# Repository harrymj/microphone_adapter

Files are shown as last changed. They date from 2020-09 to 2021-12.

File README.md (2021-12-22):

# <div align="center">Microphone Adapter</div>

[Link to project page on AJ6ME Radios Website](https://sites.google.com/aj6me.com/aj6me-radios/kw-microphone-adapter)

This project is not affiliated with Kenwood, nor endorsed by them. All references to the TM-D710GA here only indicate the personal radio the author originally designed the project for.

## Introduction
Standard solutions to enable external headsets for the TM-D710GA and similar amateur radios involve using adapter harnesses and/or large mechanical switch boxes. The handheld microphone's buttons (necessary for VFO direct entry) are not usable at the same time as the headset.

This project allows simultaneous connection of both a standard handheld microphone and a headset mic (3.5mm)/PTT (1/4") combination. A solid state audio switch automatically switches between the two microphone inputs depending on which PTT is pressed. 

The board above will be housed in an extruded aluminum enclosure with endcaps with custom cutouts for the connectors. The aluminum enclosure will be plated in a conductive material for good EMI shielding.

### Tooling
This project is designed in Altium Designer. I recognize and apologize that this isn't the most common/portable tool for open-source hardware, but it's the one that I'm the most familiar and comfortable with. Altium provides a [free, no-login web-based viewer](https://www.altium.com/viewer/) that enables viewing/probing the schematics and layout and viewing the 3D model of the finished board. The schematic is also exported as a PDF in the PCBA (assembly) manufacturing outputs folder.

A quick note about version schemes: Traditionally I've used a scheme project_name_x-y-z where x,y,z are integers incrementing from 0. X increments if there's a major architectural change to the project. Y increments if the PCB fab changes (copper/silkscreen/etc). Z changes for different component stuffing options on the same board. X and Y are tracked for the folder in the filenames, and Z is tracked as a 'variant' in the toolchain. As of now, each copper rev is stored in a different folder. If I eventually decide to get more seriously into git and try to manage releases in the tool, that may change. 

## Implementation

### Radio Connector Pinout (1:1 to Handheld Mic)
| Standard RJ45 Pin # | Kenwood Pin # | Function |
| --- | --- | --- |
| 1 | 8 | Keypad |
| 2 | 7 | Hook (GND when on hanger) |
| 3 | 6 | MIC |
| 4 | 5 | MIC-E (Shield) |
| 5 | 4 | PTT |
| 6 | 3 | GND |
| 7 | 2 | SB (8V Power Rail) |
| 8 | 1 | No Connect |

### Schematic
Allmost all signals are run through 1:1 between the Radio and Handheld Mic connector. The exceptions are:

Shield and board GND are tied together: this is also done on the radio side so there's the potential for a ground loop, but the area is only between two adjacent pairs on an RJ45 cable. As a benefit, this merging of grounds means that the enclosure (conductive aluminum) can be more effectively bonded to the shield/outer contact of all connectors, which should reduce radiated susceptibility.

Hook is not connected (though there's a resistor stuffing option to connect it if you wish). If connected, this would disable all transmit (even headset transmit) when the handheld mic is on its hanger.

The microphone signal is muxed between the handheld mic and the headset mic using a [TS5A22364DGSR](https://datasheet.ciiva.com/1671/ts5a22362-1671776.pdf?src-supplier=Digi-Key) analog switch. This switch is a single-supply (only a single positive 5V supply) analog switch that still allows for negative switched voltages (down to -500mV given the 5V supply) at low THD.

The select input of this analog switch is set using the Headset PTT signal. If the Headset PTT is pressed, the switch will connect the Headset microphone input to the radio. If the Headset PTT isn't pressed (regardless of whether the handheld mic PTT is being pressed) the handheld mic will be connected to the radio. When the headset PTT is pressed, D1 pulls down the main PTT line to key up the radio. When the handheld mic is pressed, the main PTT signal goes low (keying the radio), but because of D1, the Headset PTT line is not pulled low (ensuring the handheld mic is connected).

### Layout
The board is 4 layers. All components are placed on L1, so this is a two-step assembly process of first mounting and reflowing the SMT components, then placing and soldering (by hand, wave, selective wave, etc) the through-hole components. Surface-mount versions of these connectors do exist, but the designer generally avoids them due to mechanical robustness concerns (large connectors only mounted on surface-mount pads tend to be easier to rip out of the board than connectors that are staked through the board).

Audio signals are run (as much as feasible) on Layer 2, where they can be surrounded by GND planes on L1, L2, and L3. Ground Plane stitching vias are used to ensure these three planes stay at the same voltage.

On the two non-connector faces, grounded copper strips are exposed (likely, the sides of the boards there will be plated as well) to enable good connection to the conductive enclosure.

### Enclosure
Vendor selection and prototyping for the enclosure is still ongoing, but will take the form of an aluminum extrusion plus cutout-endplates for the connector faces. Designer is targeting a Trivalent Chromium plating on the enclosure to make it conductive for better connection to the shields of the connectors. When available, manufacturer's drawings will be uploaded.

### Board to Radio Cable
While a standard 1:1 RJ45 Ethernet cable should work here, the Keypad signal is an oscillating square-wave signal at some number of kHz. This can inject a decent chunk of noise into the radio. Testing is still ongoing to determine the best way to manage this (different pinout cable, standard shielded patch cable, shielded custom pinout patch cable, etc.)

### Manufacturing Outputs
Full sets of manufacuring files (ODB++, Gerbers/NC Drill, BOM, pick & place, schematic PDF, and 3d step file) for the PCBs are (or will be when complete) included in the respective subfolders. As referred to in the introductory note above, there are two types of manufacturing output folders: PCB (bare fab) and PCBA (assembled board). The PCB manufacturing outputs will take the form of microphone_adapter_1-y where y is the copper revision number. PCBA manufacturing outputs will take the form of microphone_adapter_1-y-z where y still represents copper revision number, and z represents component stuffing revision number.

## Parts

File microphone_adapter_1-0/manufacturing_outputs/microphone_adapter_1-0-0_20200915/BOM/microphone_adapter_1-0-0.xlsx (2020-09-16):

Designator | Quantity | Manufacturer Part Number | Description | Comment | Footprint
C1, C2 | 2 | GRM21A5C2E220JW01D | CAP CER 22PF 250V C0G/NP0 0805 | GRM21A5C2E220JW01D | C0805_1.00MM
C3, C4 | 2 | GRM155C81E105ME11D | CAP CER 1UF 25V X6S 0402 | GRM155C81E105ME11D | C0402_0.55MM
D1 | 1 | BAT54XV2T1G | ON Semi BAT54XV2T1G; SMT Schottky Diode; 30V 200mA; 5ns; 2-Pin SOD-523 | BAT54XV2T1G | SOD523_ONSEMI
J1, J2 | 2 | RJHSE-5480 | Conn RJ-45 F 8 POS 2.03mm Solder RA Thru-Hole 8 Terminal 1 Port Tray Cat 5 | RJHSE-5480 | ETH_RJ45_RA_RJHSE-5480
J3 | 1 | MJ-3536 | CONN JACK MONO 3.5MM R/A | MJ-3536 | AUD_CUI_MJ-3536
J4 | 1 | RN112BPC | CONN JACK STEREO 0.25" (6.35MM) R/A | RN112BPC | AUD_SWITCHCRAFT_RN112BPC
R1 | 1 | RC0402FR-074K7L | RES SMD 4.7K OHM 1% 1/16W 0402 | RC0402FR-074K7L | R0402_0.40MM
U1 | 1 | TS5A22364DGSR | TEXAS INSTRUMENTS TS5A22364DGSR. ANALOG SWITCH, DUAL, SPDT, MSOP-10 | TS5A22364DGSR | TI_VSSOP_10_DGS0010A
U2 | 1 | AP7370-50W5-7 | LDO Regulator Pos 5V 0.3A 5-Pin SOT-25 T/R | AP7370-50W5-7 | DIODES_INC_SOT25_5

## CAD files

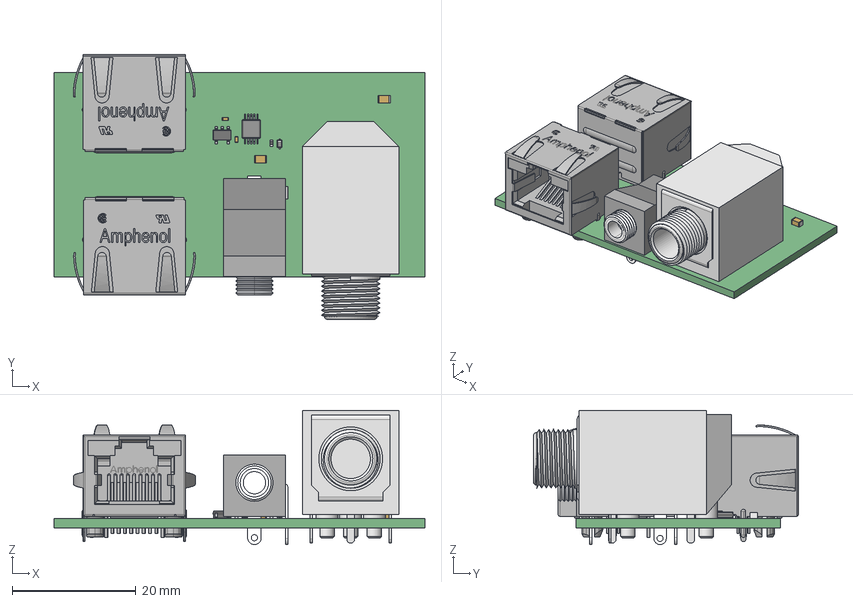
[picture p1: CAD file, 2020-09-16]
microphone_adapter_1-0/manufacturing_outputs/microphone_adapter_1-0-0_20200915/microphone_adapter_1-0-0.step
60.0 x 42.8 x 21.7 mm
RN112BPC_(1)_v1
User_Library-SOT-25
Extruded x 15
BODY-SO
LEAD-SO x 10
PIN1-ID
User_Library-SOD-523F
CUI_DEVICES_MJ-3536
ACC-M-RJHSE-5480-REVT1_RGB8421504 x 2

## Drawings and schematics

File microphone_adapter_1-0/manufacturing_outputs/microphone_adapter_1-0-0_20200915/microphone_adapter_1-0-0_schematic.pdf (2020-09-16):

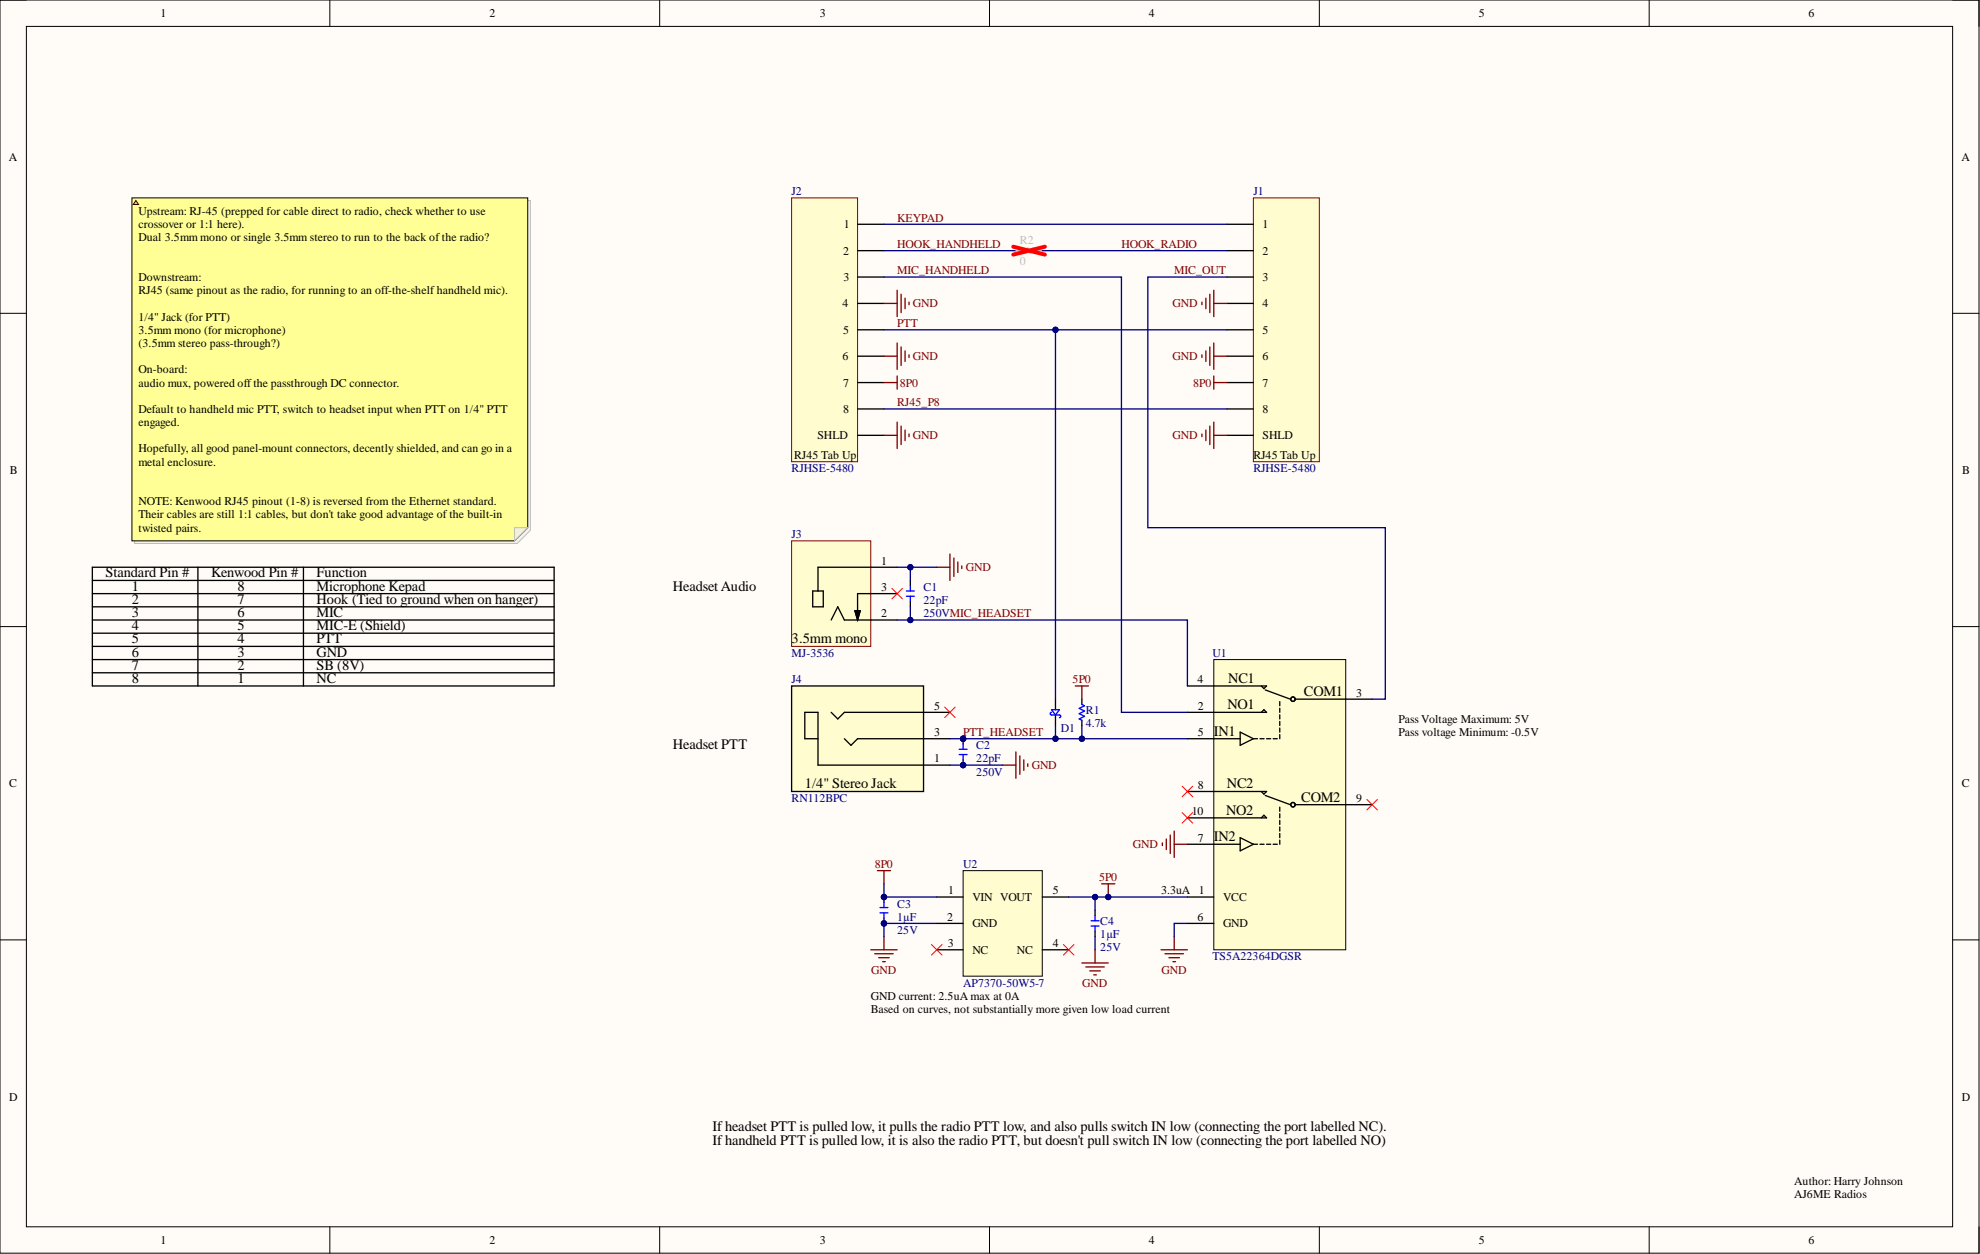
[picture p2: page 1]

Upstream: RJ-45 (prepped for cable direct to radio, check whether to use
crossover or 1:1 here).
Dual 3.5mm mono or single 3.5mm stereo to run to the back of the radio?

Downstream:
RJ45 (same pinout as the radio, for running to an off-the-shelf handheld mic).

PTT

On-board:
audio mux, powered off the passthrough DC connector.

Default to handheld mic PTT, switch to headset input when PTT on 1/4" PTT
engaged.

Hopefully, all good panel-mount connectors, decently shielded, and can go in a
metal enclosure.

NOTE: Kenwood RJ45 pinout (1-8) is reversed from the Ethernet standard.
Their cables are still 1:1 cables, but don't take good advantage of the built-in
twisted pairs.

2 | 7 | Hook (Tied to ground when on hanger)
3 | 6 | MIC
4 | 5 | MIC-E (Shield)
5 | 4 | PTT
6 | 3 | GND

8 | Microphone Kepad

GND current: 2.5uA max at 0A
Based on curves, not substantially more given low load current

If headset PTT is pulled low, it pulls the radio PTT low, and also pulls switch IN low (connecting the port labelled NC).
If handheld PTT is pulled low, it is also the radio PTT, but doesn't pull switch IN low (connecting the port labelled NO)

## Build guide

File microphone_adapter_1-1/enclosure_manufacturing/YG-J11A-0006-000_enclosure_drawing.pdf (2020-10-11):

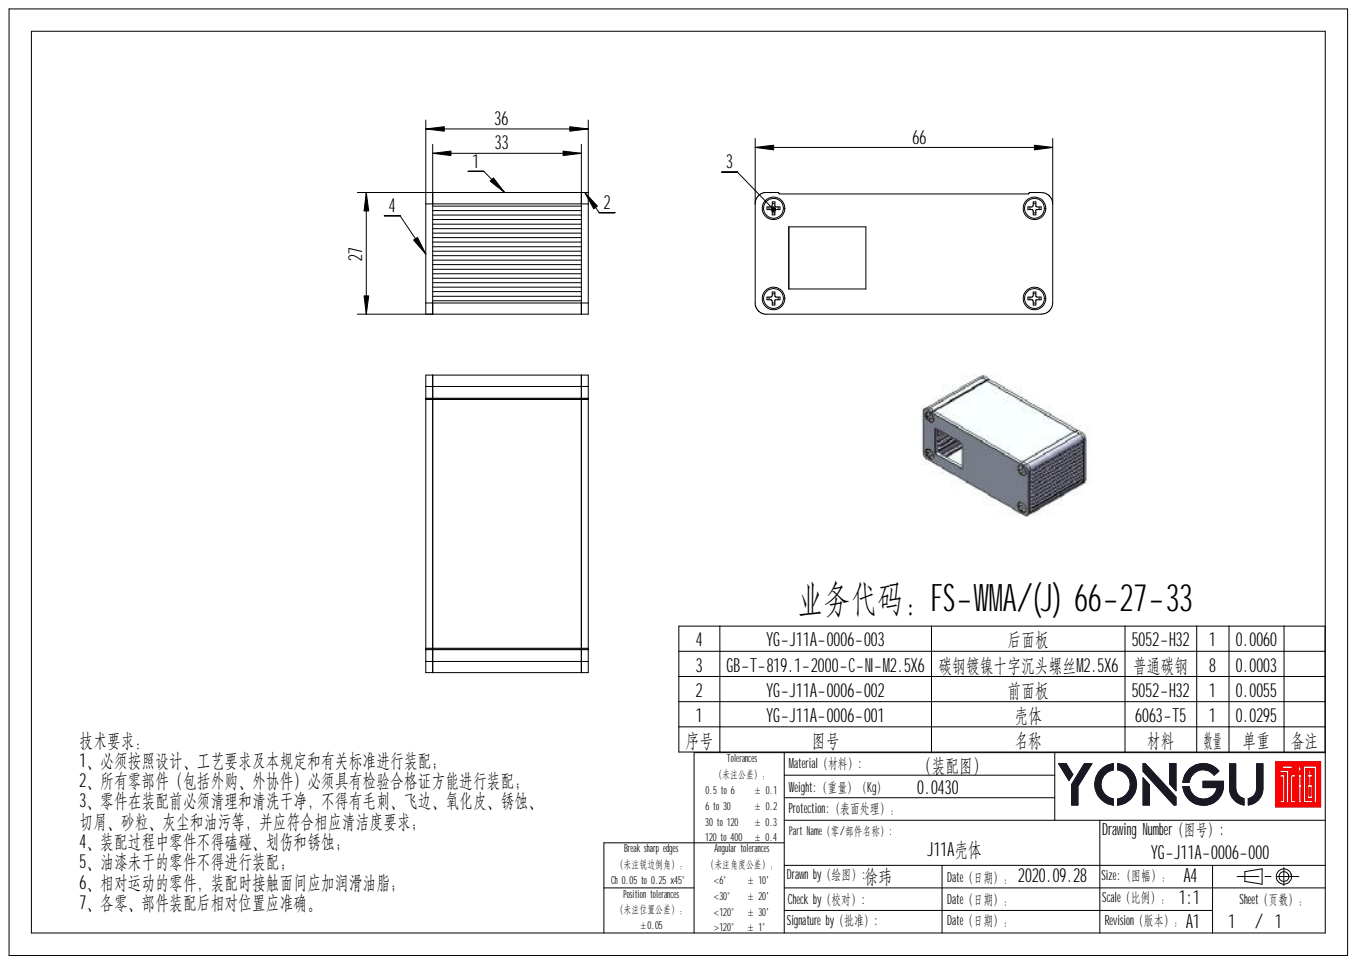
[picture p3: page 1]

业务代码：FS-WMA/(J) 66-27-33

4 | YG-J11A-0006-003 | 后面板 | 5052-H32 | 1 | 0.0060
3 | GB-T-819.1-2000-C-NI-M2.5X6 | 碳钢镀镍十字沉头螺丝M2.5X6 | 普通碳钢 | 8 | 0.0003
2 | YG-J11A-0006-002 | 前面板 | 5052-H32 | 1 | 0.0055
1 | YG-J11A-0006-001 | 壳体 | 6063-T5 | 1 | 0.0295
序号 | 图号 | 名称 | 材料 | 数量 | 单重 | 备注
Tolerances （未注公差）： 0.5 to 6 ± 0.1 6 to 30 ± 0.2 30 to 120 ± 0.3 120 to 400 ± 0.4 | Material（材料）: （装配图）

技术要求：
1、必须按照设计、工艺要求及本规定和有关标准进行装配；
2、所有零部件（包括外购、外协件）必须具有检验合格证方能进行装配；
3、零件在装配前必须清理和清洗干净，不得有毛刺、飞边、氧化皮、锈蚀、
切屑、砂粒、灰尘和油污等，并应符合相应清洁度要求；
4、装配过程中零件不得磕碰、划伤和锈蚀；
5、油漆未干的零件不得进行装配；
6、相对运动的零件，装配时接触面间应加润滑油脂；
7、各零、部件装配后相对位置应准确。

Weight:（重量）（Kg）
Protection:（表面处理）：

Part Name（零/部件名称）: J11A壳体 | Drawing Number（图号）: YG-J11A-0006-000

Break sharp edges （未注锐边倒角）： Ch 0.05 to 0.25 x45° | Angular tolerances （未注角度公差）： <6° ± 10' <30° ± 20'

Drawn by（绘图）: 徐玮 | 2020.09.28 Date（日期）： | Size:（图幅）： A4

Position tolerances （未注位置公差）： ±0.05 | | Check by（校对）: | Date（日期）： | 1:1 Scale（比例）： | Sheet（页数）：

Signature by（批准）: | Date（日期）： | Revision（版本）： A1

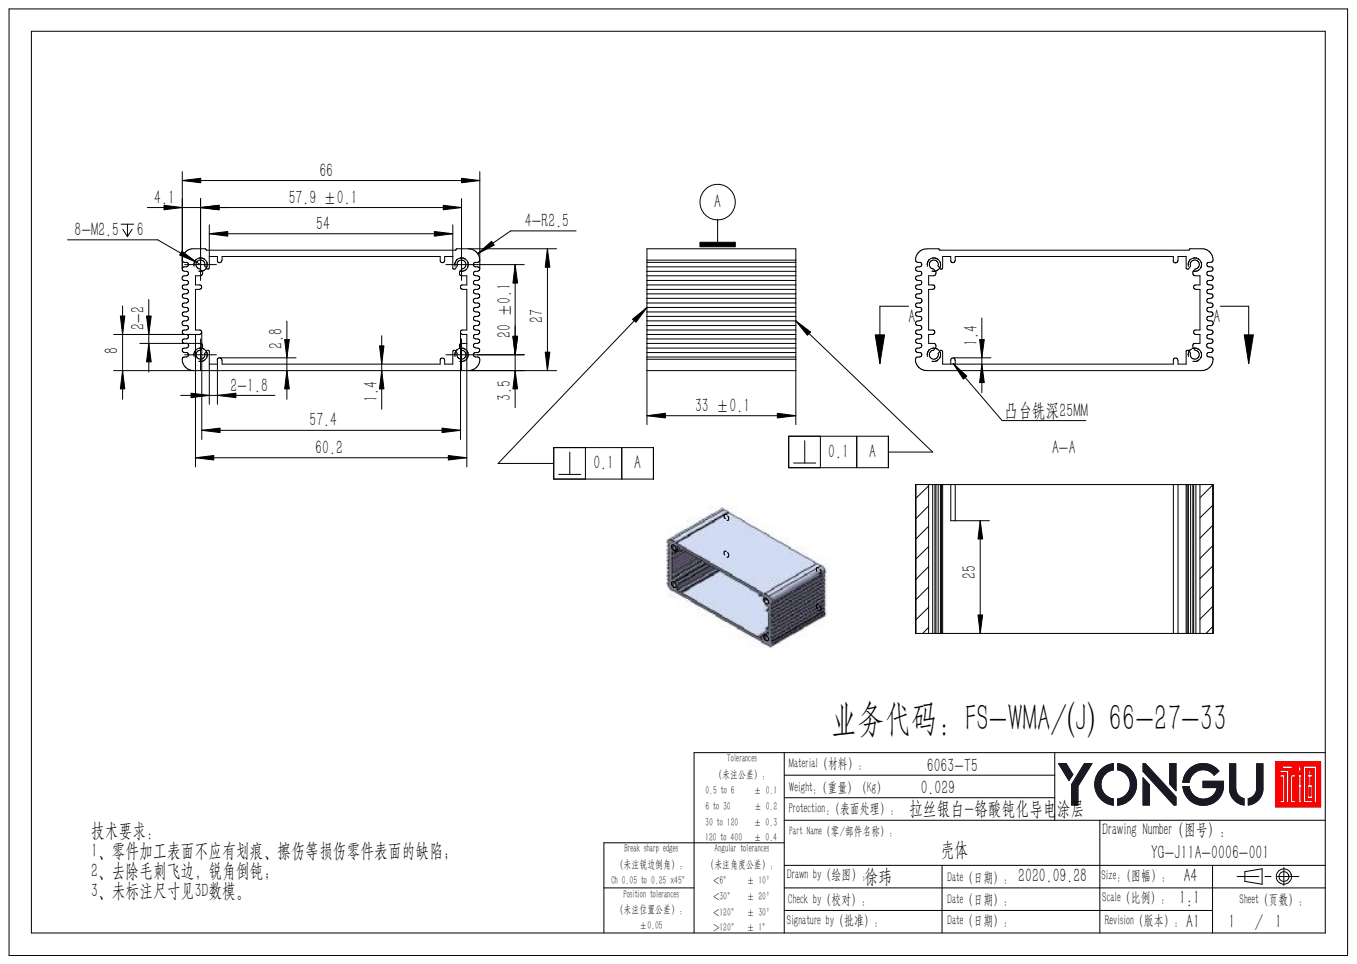
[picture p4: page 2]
Tolerances （未注公差）：; 拉丝银白-铬酸钝化导电涂层; 凸台铣深25MM; 3、未标注尺寸见3D数模。; 技术要求： 1、零件加工表面不应有划痕、擦伤等损伤零件表面的缺陷； 2、去除毛刺飞边，锐角倒钝；

业务代码：FS-WMA/(J) 66-27-33

Material（材料）:
Weight:（重量）（Kg）
Protection:（表面处理）：

Part Name（零/部件名称）: 壳体 | Drawing Number（图号）: YG-J11A-0006-001
Break sharp edges （未注锐边倒角）： Ch 0.05 to 0.25 x45° | Angular tolerances （未注角度公差）： <6° ± 10' <30° ± 20'

Drawn by（绘图）: 徐玮 | 2020.09.28 Date（日期）： | Size:（图幅）： A4
Position tolerances ±0.05 | | Check by（校对）: | Date（日期）： | 1:1 Scale（比例）： | Sheet（页数）： /

Revision（版本）： >120° ± 1° A1

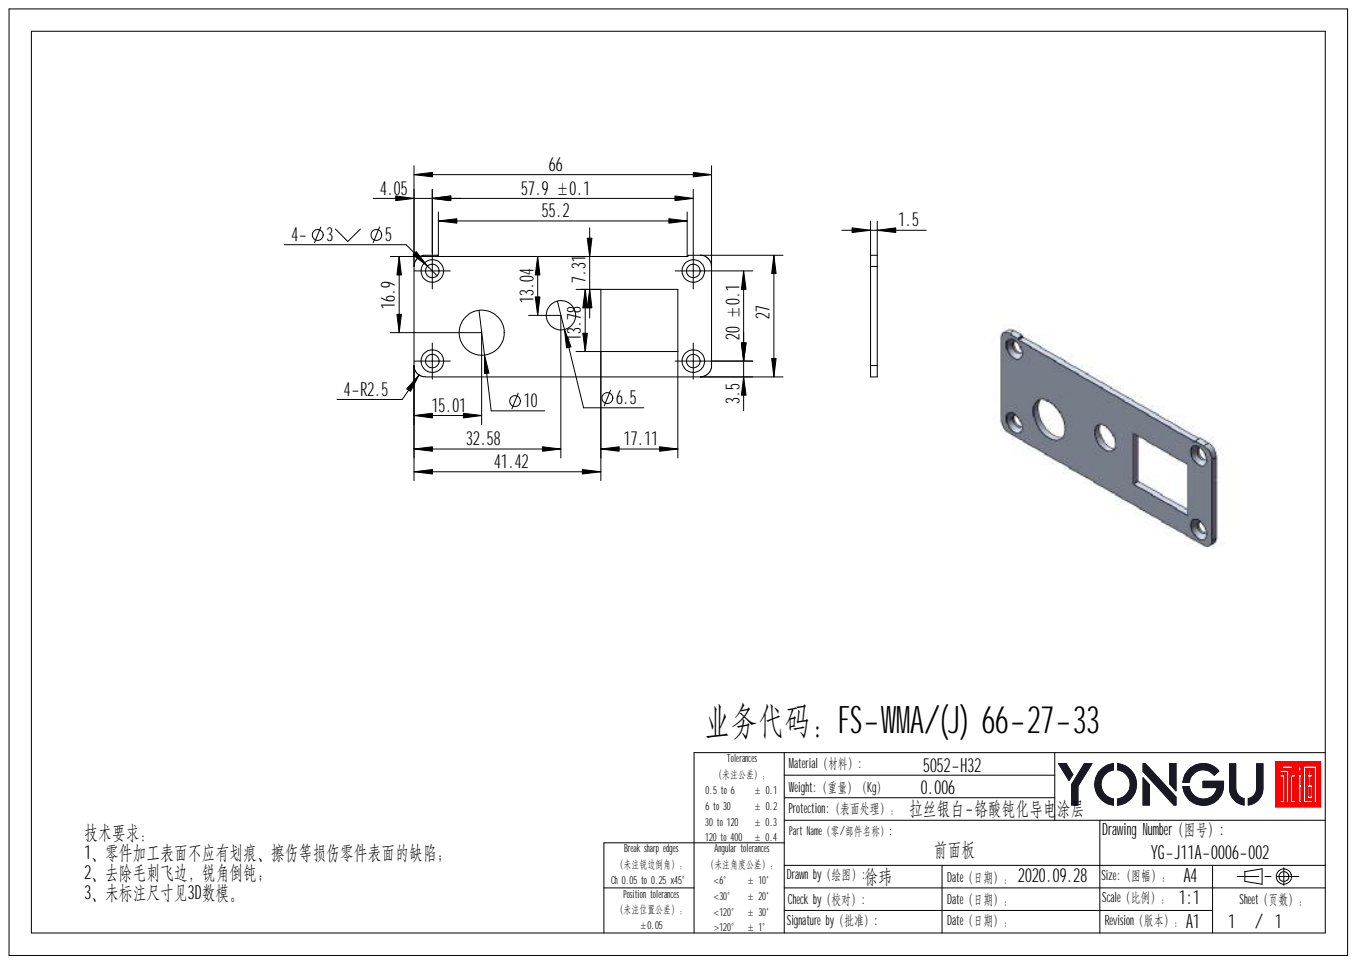
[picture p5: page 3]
Tolerances （未注公差）：; 拉丝银白-铬酸钝化导电涂层; 3、未标注尺寸见3D数模。; 技术要求： 1、零件加工表面不应有划痕、擦伤等损伤零件表面的缺陷； 2、去除毛刺飞边，锐角倒钝；

业务代码：FS-WMA/(J) 66-27-33

Material（材料）:
Weight:（重量）（Kg）
Protection:（表面处理）：

Part Name（零/部件名称）: 前面板 | Drawing Number（图号）: YG-J11A-0006-002

Break sharp edges （未注锐边倒角）： Ch 0.05 to 0.25 x45° | Angular tolerances （未注角度公差）： <6° ± 10' <30° ± 20'

Drawn by（绘图）: 徐玮 | 2020.09.28 Date（日期）： | Size:（图幅）： A4

Position tolerances | | Check by（校对）: | Date（日期）： | 1:1 Scale（比例）： | Sheet（页数）： 1 / 1

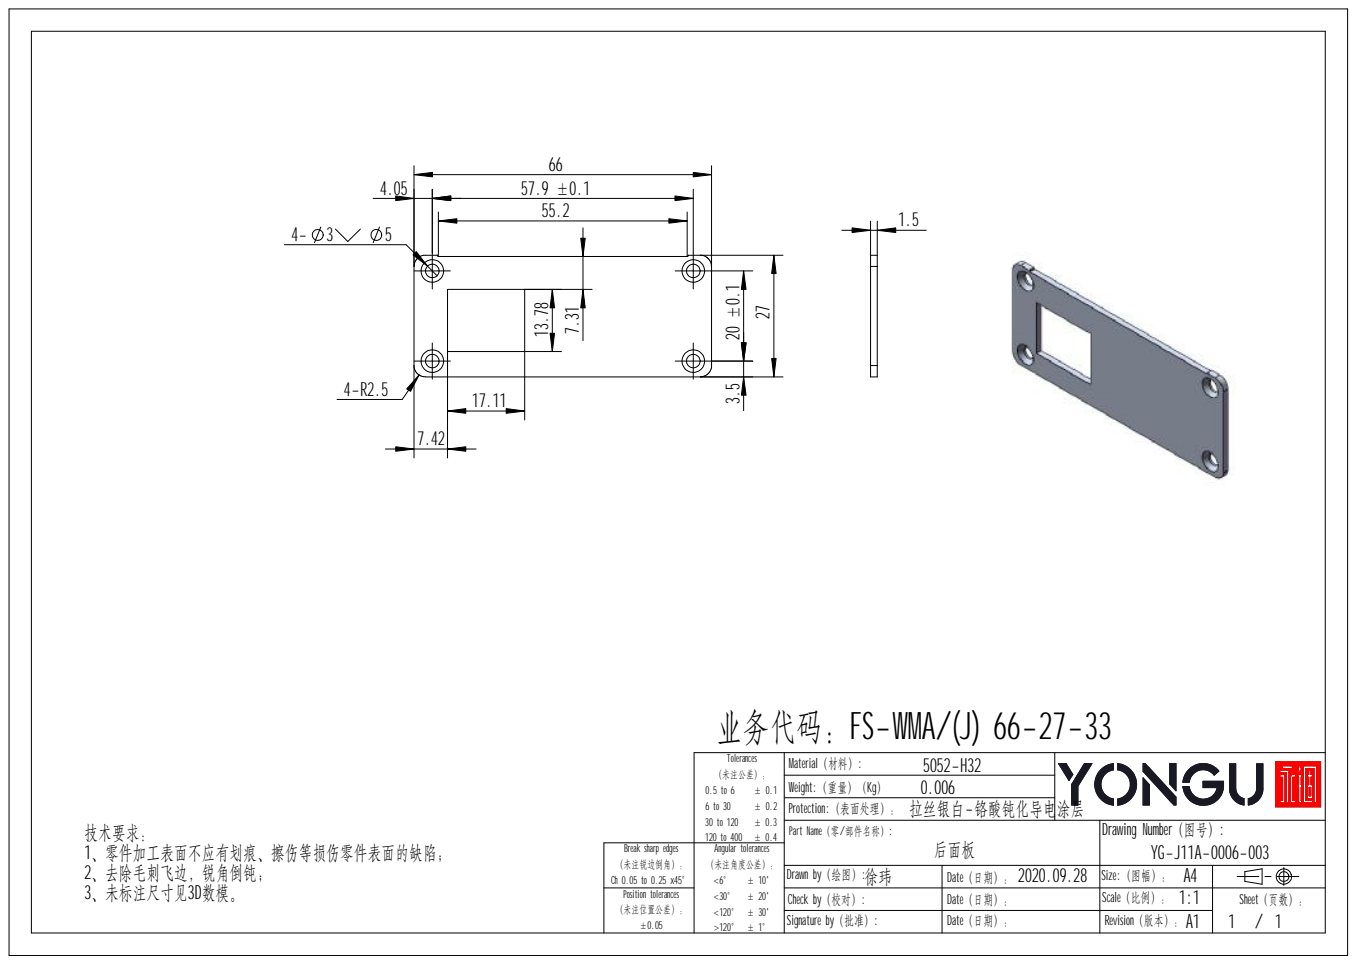
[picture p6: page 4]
Tolerances （未注公差）：; 拉丝银白-铬酸钝化导电涂层; 3、未标注尺寸见3D数模。; 技术要求： 1、零件加工表面不应有划痕、擦伤等损伤零件表面的缺陷； 2、去除毛刺飞边，锐角倒钝；

业务代码：FS-WMA/(J) 66-27-33

Material（材料）:
Weight:（重量）（Kg）
Protection:（表面处理）：

Part Name（零/部件名称）: 后面板 | Drawing Number（图号）: YG-J11A-0006-003

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

Drawn by（绘图）: 徐玮 | 2020.09.28 Date（日期）： | Size:（图幅）： A4

Position tolerances | | Check by（校对）: | Date（日期）： | 1:1 Scale（比例）： | Sheet（页数）：

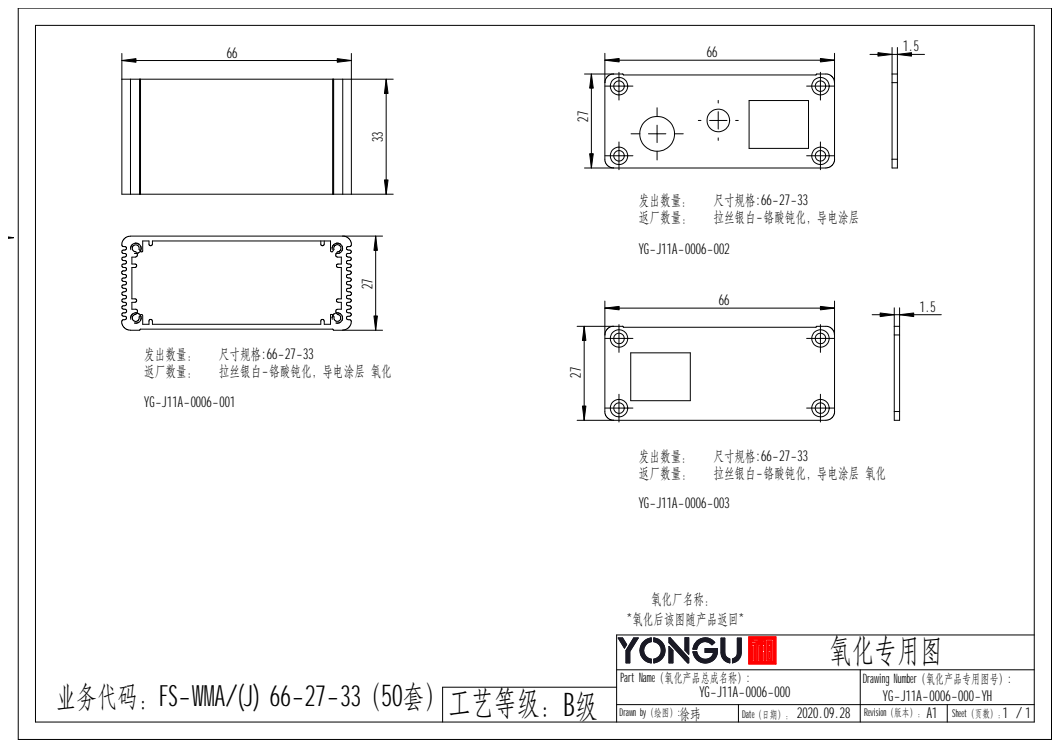
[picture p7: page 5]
*氧化后该图随产品返回*; 氧化厂名称：; 工艺等级：; 氧化专用图; 返厂数量：; 拉丝银白-铬酸钝化，导电涂层 氧化; 发出数量：; 尺寸规格:66-27-33; 拉丝银白-铬酸钝化，导电涂层

Part Name（氧化产品总成名称）: YG-J11A-0006-000 | Drawing Number（氧化产品专用图号）: YG-J11A-0006-000-YH

业务代码：FS-WMA/(J) 66-27-33

Drawn by（绘图）: 徐玮 | Date（日期）： 2020.09.28 | Revision（版本）： | Sheet（页数）： 1 /1

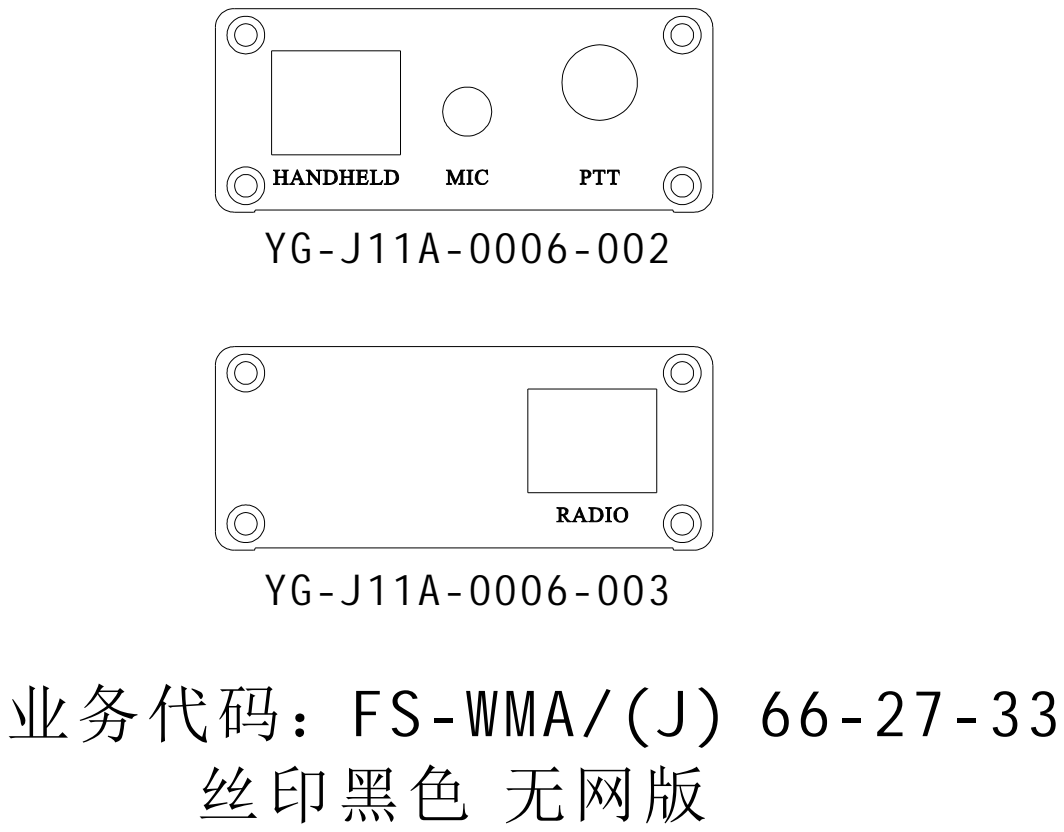
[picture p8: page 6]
丝印黑

业务代码：FS-WMA/(J) 66-27-33

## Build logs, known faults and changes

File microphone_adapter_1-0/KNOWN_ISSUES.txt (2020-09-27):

Known issues with microphone_adapter_1-0:
1) Solder mask/paste mask on U2 (5V LDO) is not set by rule due to bad library addition, so the pads are masked over. Addressed in microphone_adapter_1-1-0 and beyond.
2) Edge of 6.35mm audio jack interferes with a feature on the lid of the enclosure (the board mount for the 90 degree board option). Need to move that connector by 2mm.

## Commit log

2020-08-29 Schematic: Add RJ45 pin number info
    Add information about Kenwood and standard RJ45 pin numbers and function.
    [microphone_adapter_top.SchDoc]
2020-08-29 top.SchDoc: Add some options for connector choices.
    [microphone_adapter_top.SchDoc]
2020-08-30 Add connectors and placeholder PCB.
    Added the set of placeholder connectors (2x RJ45, 1x 3.5mm mono, 1x 1/4" PTT) to schematics and PCB, to get rough testimate of board size (2.2 x 1.1")
    [microphone_adapter_1-0.PcbDoc, microphone_adapter_top.SchDoc]
2020-08-30 Add in pass-through nets.
    [microphone_adapter_1-0.PcbDoc, microphone_adapter_1-0.PrjPcb, microphone_adapter_top.SchDoc]
2020-09-07 New switch+LDO, layout, outjob.
    Changed to a new switch that includes below-GND switching, this also requires an external 5V LDO. Layout to match, and outjob added.
    [microphone_adapter_1-0.PcbDoc, microphone_adapter_1-0.PrjPcb, microphone_adapter_top.SchDoc]
2020-09-07 Silkscreen updates.
    [microphone_adapter_1-0.PcbDoc]
2020-09-07 Shifted some silkscreen.
    [microphone_adapter_1-0.PcbDoc]
2020-09-13 Changed from mounting holes to slide rails.
    Planning around http://www.yonggu-enclosure.com/product/details/id/57.html of appropriate length for the enclosure.
    [microphone_adapter_1-0.PcbDoc, microphone_adapter_top.SchDoc]
2020-09-15 HOOK resistor & layout/variant. Tweaked Outjob.
    [microphone_adapter_1-0.PcbDoc, microphone_adapter_1-0.PrjPcb, microphone_adapter_top.SchDoc]
2020-09-16 Manufacturing outputs for microphone_adapter_1-0-0
    Gerbers, Drill File, Pick Place, BOM, ODB++, schematic PDF, and 3d step file.
    [microphone_adapter_1-0-0.GBL, microphone_adapter_1-0-0.GBO, microphone_adapter_1-0-0.GBP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]
2020-09-16 RJ45s were reversed from each other. Corrected and updated files.
    [microphone_adapter_1-0-0.GBL, microphone_adapter_1-0-0.GBO, microphone_adapter_1-0-0.GBP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]
2020-09-24 First commit of microphone_adapter_1-1, cleanup to 1-0
    Rev 1-1-0 changes:
    Fix soldermask on U2 pads.
    De-pop filtering capacitors.
    [microphone_adapter_1-0.PcbDoc, microphone_adapter_1-1.PcbDoc, microphone_adapter_1-1.PrjPcb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]
2020-09-26 PCB: Update rev silkscreen. Schematic: Fix ERC markers. Outjob: Use Variables
    Schematic: Made the no-ERC directives also ignore single-pin net errors. This had been masked before by a transient Altium bug where a no-ERC directive would actually suppress all ERC errors, even if you'd set it to specific errors only.
    PCB: Updated silkscreen to match board rev.
    Outjob: Use project variable names and MajorRev variables to generate file names, instead of hardcoding. Will make this outjob more portable for the future.
    [microphone_adapter_1-1.PcbDoc, microphone_adapter_1-1.PrjPcb, microphone_adapter_top.SchDoc]
2020-09-27 Adding README.md, LICENSE.txt, adding license info to PCB.
    Adding README and licensing (under TAPR Open Hardware License).
    Adding licening information to the PCB (bottom layer silkscreen) as required by license.
    [microphone_adapter_1-1.PcbDoc, microphone_adapter_1-1.PrjPcb]
2020-09-27 README.md: Add note about board to radio cable.
2020-09-27 microphone_adapter_1-1: Move all connectors except RJ45s left by 2mm.
    The 6.35mm audio jack slightly interferes with a feature on the lid of the enclosure, and needs to move left by 2mm. This propagates to the 3.5mm connector and the mux circuitry as well.
    Add a warning about this to KNOWN_ISSUES.txt for 1-0.
    [microphone_adapter_1-1.PcbDoc]
2020-09-28 PCB/Variants: Switch Mic/PTT filtering to stuffed 47pF, full L1 GND pour.
    In light of some cross-coupling noise (I think from the keypad signal), full L1 ground pour (which I think I'd wanted to do anyway but forgotten), tweaks to the layout to keep the microphone signals clear and buried, and add 47pF filtering caps to PTT and headset audio for good measure.
    [microphone_adapter_1-1.PcbDoc, microphone_adapter_1-1.PrjPcb, microphone_adapter_top.SchDoc]
2020-09-28 Add manufacturing outputs for 1-1-0 PCB and PCBA, plus a note about version numbering
    Manufacturing data (inc. PDF view of schematic) for 1-1-0.
    Updated the README to talk about the use of Altium, link to their online viewer, and add a discussion of manufacturing outputs.
    [microphone_adapter_1-1-0.step, microphone_adapter_1-1-0.xlsx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]
2020-10-11 microphone_adapter_1-1: New push of mfg files, plus enclosure drawings.
    Made some nets into testpoints and added enclosure drawing PDF.
    [microphone_adapter_1-1-0.step, microphone_adapter_1-1-0.xlsx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]
2020-10-15 microphone_adapter_1-1: Removing manufacturing outputs, have more work to do after test of first rev.
    [microphone_adapter_1-1-0.step, microphone_adapter_1-1-0.xlsx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]
2021-12-22 Canonical Commit - matching to local files.
    [microphone_adapter_1-1.PcbDoc, microphone_adapter_1-1.PrjPcb, microphone_adapter_top.SchDoc]
